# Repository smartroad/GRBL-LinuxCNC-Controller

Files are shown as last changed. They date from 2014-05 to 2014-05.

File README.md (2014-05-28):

GRBL-LinuxCNC-Controller
========================

Dual purpose controller to work with Arduino GRBL and Parallel port LinuxCNC

This controller is meant to be dual use. It can be used on the Arduino GRBL platform but can also be used with the LinuxCNC software via a parallel port.

It uses 3 Pololu or Stepstick drivers for XYZ steppers.

This hasn't yet been produced or made so it is totally possible that it doesn't work!

The design allows for 3 axis of movement, 3 limit/home switches, spindle activation and direction control.

Along on side there is a row of LEDs, these are connected to the enable, step and dir lines for the stepper drivers. While I could probably justify thier inclusion, honestly? I put them there as I love blinking lights as the machine moves ;)

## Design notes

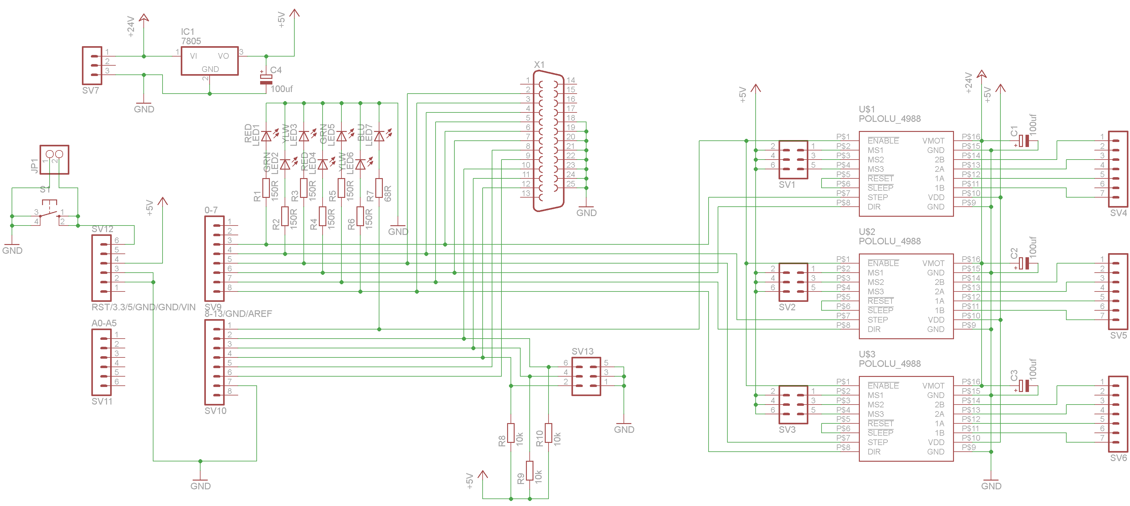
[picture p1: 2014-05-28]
Circuit Diagram.png

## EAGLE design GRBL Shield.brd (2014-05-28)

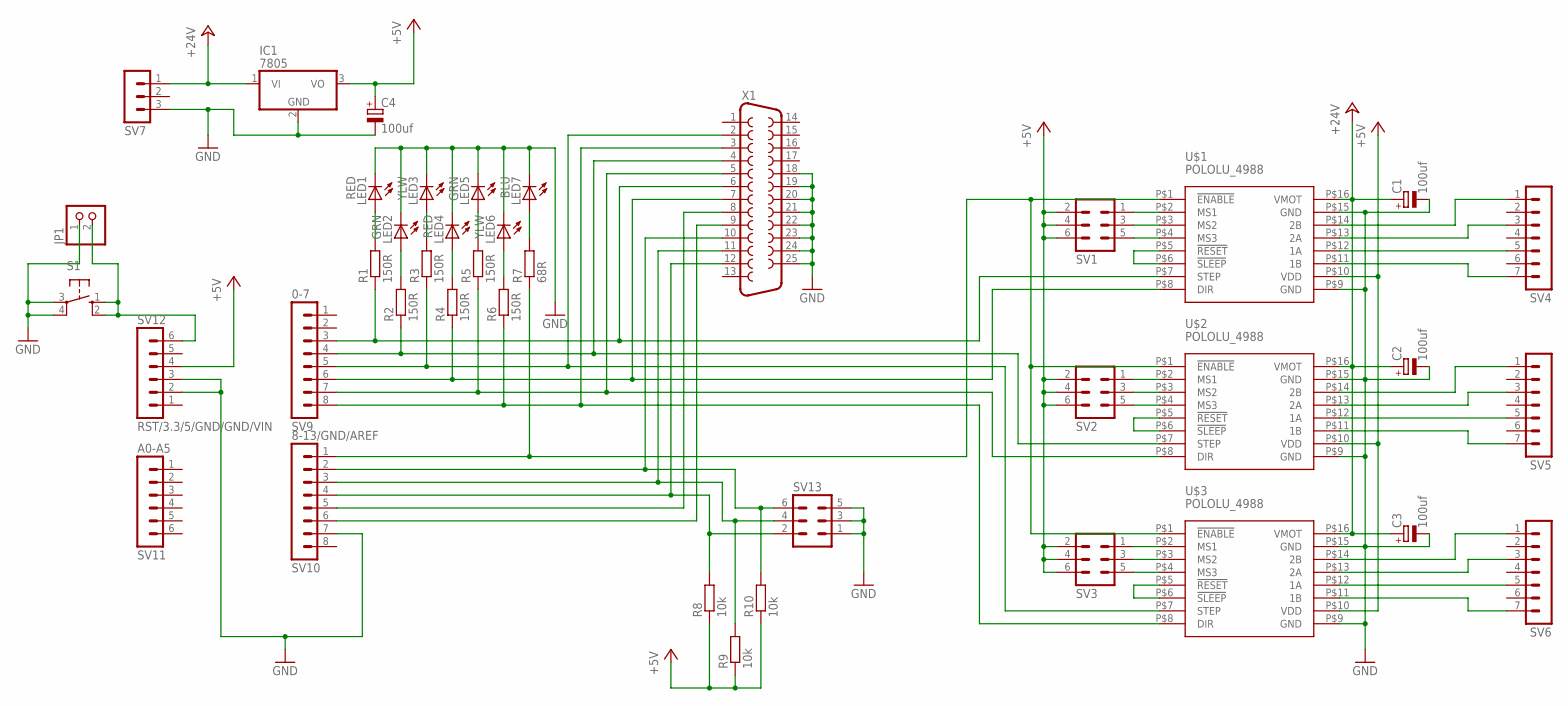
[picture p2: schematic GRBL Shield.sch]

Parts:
C1, C2, C3, C4: 100uf; E2,5-7
IC1: 7805; TO220V
JP1: PINHD-1X2; 1X02
LED1, LED4: RED; LED5MM
LED2, LED5: GRN; LED5MM
LED3, LED6: YLW; LED5MM
LED7: BLU; LED5MM
R1, R2, R3, R4, R5, R6: 150R; 0207/2V
R7: 68R; 0207/2V
R8, R9, R10: 10k; 0204/7
S1: 10-XX; B3F-10XX
SV1, SV2, SV3, SV13: MA03-2
SV4, SV5, SV6: MA07-1
SV7: MA03-1
SV9: 0-7; MA08-1
SV10: 8-13/GND/AREF; MA08-1
SV11: A0-A5; MA06-1
SV12: RST/3.3/5/GND/GND/VIN; MA06-1
U$1, U$2, U$3: POLOLU_4988
X1: F25H

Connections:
+5V: C4.+, IC1.3 (VO), R8.1, R9.1, R10.1, SV1.2, SV1.4, SV1.6, SV2.2, SV2.4, SV2.6, SV3.2, SV3.4, SV3.6, SV12.4, U$1.P$10 (VDD), U$2.P$10 (VDD), U$3.P$10 (VDD)
+24V: C1.+, C2.+, C3.+, IC1.1 (VI), SV7.1, U$1.P$16 (VMOT), U$2.P$16 (VMOT), U$3.P$16 (VMOT)
D2: R1.1, SV9.3, U$1.P$7 (STEP), X1.6
D3: R2.1, SV9.4, U$2.P$7 (STEP), X1.4
D4: R3.1, SV9.5, U$3.P$7 (STEP), X1.2
D5: R4.1, SV9.6, U$1.P$8 (DIR), X1.7
D6: R5.1, SV9.7, U$2.P$8 (DIR), X1.5
D7: R6.1, SV9.8, U$3.P$8 (DIR), X1.3
D8: R7.1, SV10.1, U$1.P$1 (!ENABLE), U$2.P$1 (!ENABLE), U$3.P$1 (!ENABLE)
D9: R10.2, SV10.2, SV13.6, X1.10
D10: R9.2, SV10.3, SV13.4, X1.11
D11: R8.2, SV10.4, SV13.2, X1.12
D12: SV10.5, X1.8
D13: SV10.6, X1.9
GND: C1.-, C2.-, C3.-, C4.-, IC1.2 (GND), JP1.1, LED1.K (C), LED2.K (C), LED3.K (C), LED4.K (C), LED5.K (C), LED6.K (C), LED7.K (C), S1.3, S1.4 (P1), SV7.3, SV10.7, SV12.2, SV12.3, SV13.1, SV13.3, SV13.5, U$1.P$9 (GND), U$1.P$15 (GND), U$2.P$9 (GND), U$2.P$15 (GND), U$3.P$9 (GND), U$3.P$15 (GND), X1.18, X1.19, X1.20, X1.21, X1.22, X1.23, X1.24, X1.25
unnamed: U$1.P$5 (!RESET), U$1.P$6 (!SLEEP)
unnamed: U$2.P$5 (!RESET), U$2.P$6 (!SLEEP)
unnamed: U$3.P$5 (!RESET), U$3.P$6 (!SLEEP)
unnamed: SV1.1, U$1.P$2 (MS1)
unnamed: SV1.3, U$1.P$3 (MS2)
unnamed: SV1.5, U$1.P$4 (MS3)
unnamed: SV2.1, U$2.P$2 (MS1)
unnamed: SV2.3, U$2.P$3 (MS2)
unnamed: SV2.5, U$2.P$4 (MS3)
unnamed: SV3.1, U$3.P$2 (MS1)
unnamed: SV3.3, U$3.P$3 (MS2)
unnamed: SV3.5, U$3.P$4 (MS3)
unnamed: SV4.1, U$1.P$14 (2B)
unnamed: SV4.3, U$1.P$13 (2A)
unnamed: SV4.5, U$1.P$12 (1A)
unnamed: SV4.7, U$1.P$11 (1B)
unnamed: SV5.1, U$2.P$14 (2B)
unnamed: SV5.3, U$2.P$13 (2A)
unnamed: SV5.5, U$2.P$12 (1A)
unnamed: SV5.7, U$2.P$11 (1B)
unnamed: SV6.1, U$3.P$14 (2B)
unnamed: SV6.3, U$3.P$13 (2A)
unnamed: SV6.5, U$3.P$12 (1A)
unnamed: SV6.7, U$3.P$11 (1B)
unnamed: LED1.A, R1.2
unnamed: LED2.A, R2.2
unnamed: LED3.A, R3.2
unnamed: LED4.A, R4.2
unnamed: LED5.A, R5.2
unnamed: LED6.A, R6.2
unnamed: LED7.A, R7.2
RESET: JP1.2, S1.1 (S), S1.2 (S1), SV12.6

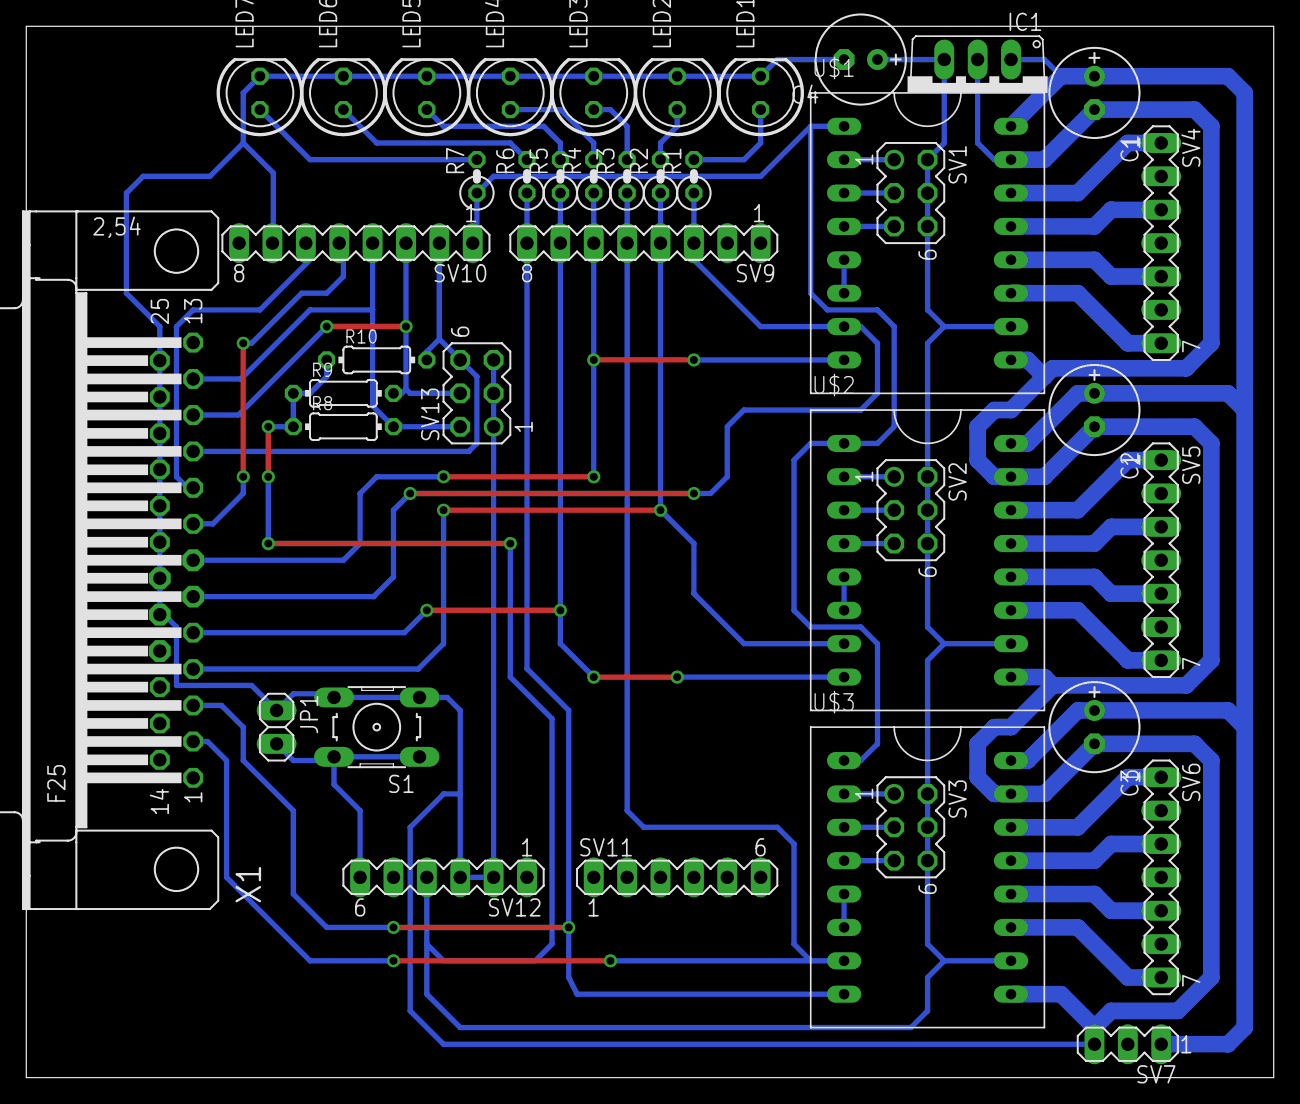
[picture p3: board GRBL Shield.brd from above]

Board: 2 copper layers, 94.9 x 80.0 mm, 40 parts (0 on the bottom side), 47 nets.

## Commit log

2014-05-28 Circuit Diagram image
2014-05-28 Added values for components and added 5V regulator #1
    [GRBL Shield.brd, GRBL Shield.sch]
